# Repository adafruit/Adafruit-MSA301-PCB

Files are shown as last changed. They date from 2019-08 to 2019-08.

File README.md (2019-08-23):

## Adafruit MSA301 Triple Axis Accelerometer PCB

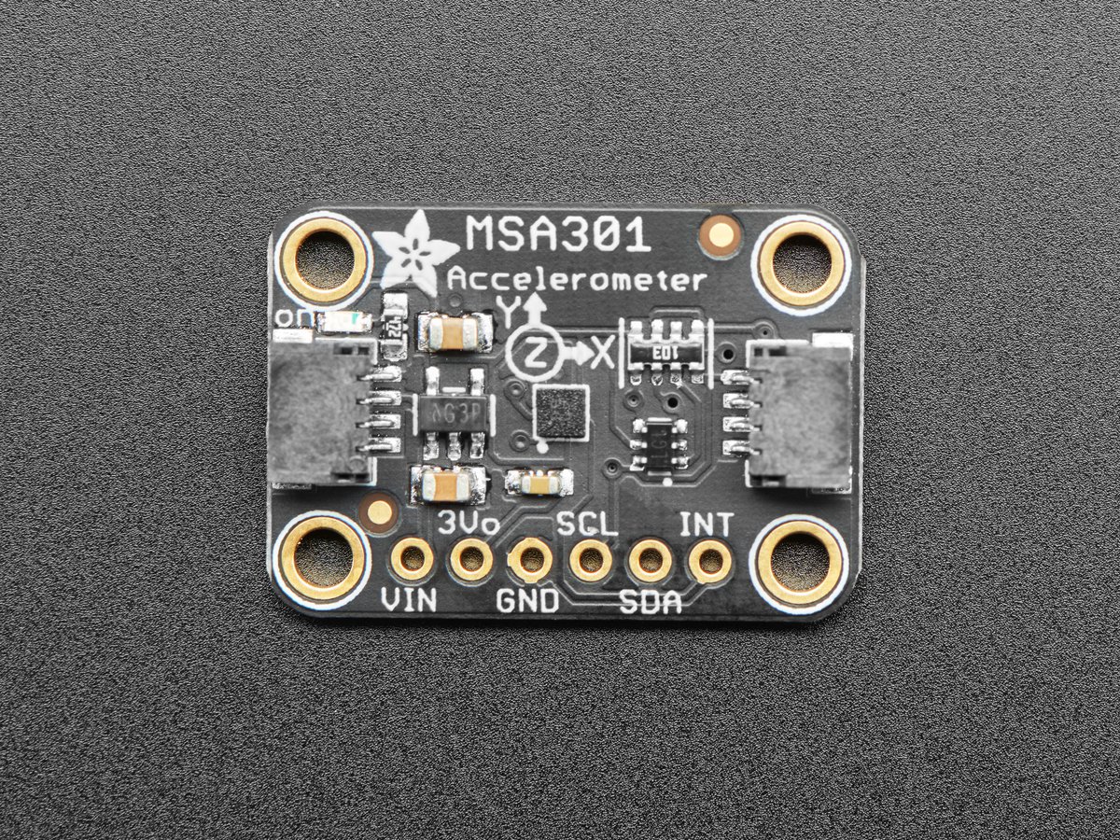
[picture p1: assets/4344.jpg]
<a href="http://www.adafruit.com/products/4344"><br/>
Click here to purchase one from the Adafruit shop</a>

PCB files for the Adafruit MSA301 Triple Axis Accelerometer. 

Format is EagleCAD schematic and board layout
* https://www.adafruit.com/product/4344

### Description

The MSA301 is a super small and low cost **triple-axis accelerometer**. It's inexpensive, but has just about every 'extra' you'd want in an accelerometer:

* Three axis sensing, 14-bit resolution
* ±2g/±4g/±8g/±16g selectable scaling
* I2C interface on fixed I2C address 0x26
* Interrupt output
* Multiple data rate options 1 Hz to 500 Hz
* As low as 2uA current draw in low power mode (just the chip itself, not including any supporting circuitry)
* Tap, Double-tap, orientation & freefall detection
To make life easier so you can focus on your important work, we've taken the MSA301 and put it onto a breakout PCB along with support circuitry to let you use this little wonder with 3.3V (Feather/Raspberry Pi) or 5V (Arduino/ Metro328) logic levels. Additionally since it speaks I2C you can easily connect it up with two wires (plus power and ground!).  We've even included [SparkFun qwiic](https://www.sparkfun.com/qwiic) compatible [STEMMA QT](https://learn.adafruit.com/introducing-adafruit-stemma-qt) connectors for the I2C bus so **you don't even need to solder!** Just wire up to your favorite micro and you can use our [CircuitPython/Python](https://github.com/adafruit/Adafruit_CircuitPython_MSA301) or [Arduino drivers](https://github.com/adafruit/Adafruit_MSA301] to easily interface with the MSA301 and get motion measurements ASAP.

### License

Adafruit invests time and resources providing this open source design, please support Adafruit and open-source hardware by purchasing products from [Adafruit](https://www.adafruit.com)!

Designed by Limor Fried/Ladyada for Adafruit Industries.

Creative Commons Attribution/Share-Alike, all text above must be included in any redistribution. 
See license.txt for additional details.

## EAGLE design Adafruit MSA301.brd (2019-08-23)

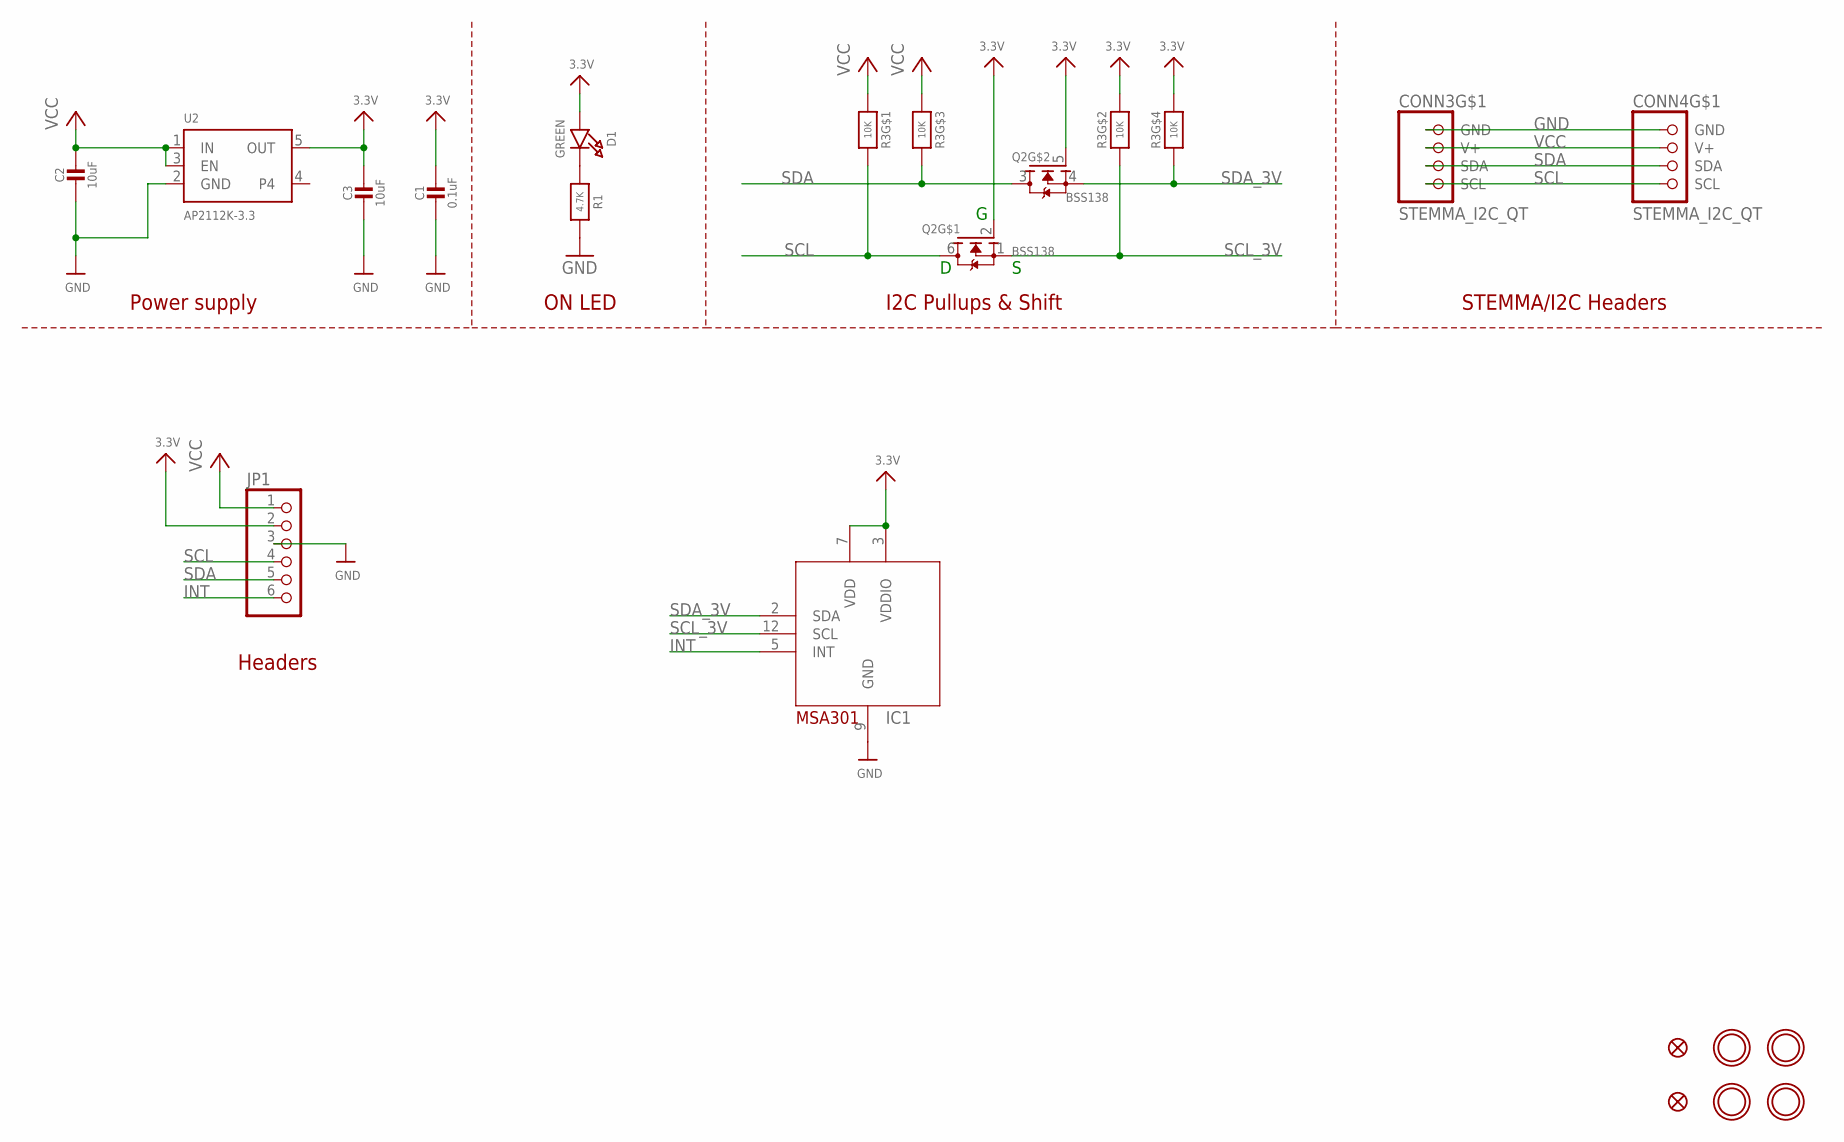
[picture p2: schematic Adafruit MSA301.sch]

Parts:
C1: 0.1uF; 0603-NO
C2, C3: 10uF; 0805-NO
CONN3, CONN4: STEMMA_I2C_QT; JST_SH4
D1: GREEN; CHIPLED_0603_NOOUTLINE
FID3, FID4: FIDUCIAL_1MM
IC1: MSA301; LGA12_2X2MM
JP1: HEADER-1X670MIL; 1X06_ROUND_70
Q2: BSS138; SOT363
R1: 4.7K; 0603-NO
R3: 10K; RESPACK_4X0603
U2: AP2112K-3.3; SOT23-5
U$1, U$17, U$19, U$21: MOUNTINGHOLE2.5; MOUNTINGHOLE_2.5_PLATED

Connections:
3.3V: C1.1, C3.1, D1.A, IC1.3 (VDDIO), IC1.7 (VDD), JP1.2, Q2.2 (G), Q2.5 (G), R3.2 (1), R3.4 (1), U2.5 (OUT)
GND: C1.2, C2.2, C3.2, CONN3.1 (GND), CONN4.1 (GND), IC1.9 (GND), JP1.3, R1.2, U2.2 (GND)
INT: IC1.5 (INT), JP1.6
unnamed: D1.C, R1.1
SCL: CONN3.4 (SCL), CONN4.4 (SCL), JP1.4, Q2.6 (D), R3.8 (2)
SCL_3V: IC1.12 (SCL), Q2.1 (S), R3.7 (2)
SDA: CONN3.3 (SDA), CONN4.3 (SDA), JP1.5, Q2.3 (D), R3.6 (2)
SDA_3V: IC1.2 (SDA), Q2.4 (S), R3.5 (2)
VCC: C2.1, CONN3.2 (V+), CONN4.2 (V+), JP1.1, R3.1, R3.3 (1), U2.1 (IN), U2.3 (EN)

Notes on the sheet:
Power supply
I2C Pullups & Shift
STEMMA/I2C Headers
Headers
ON LED

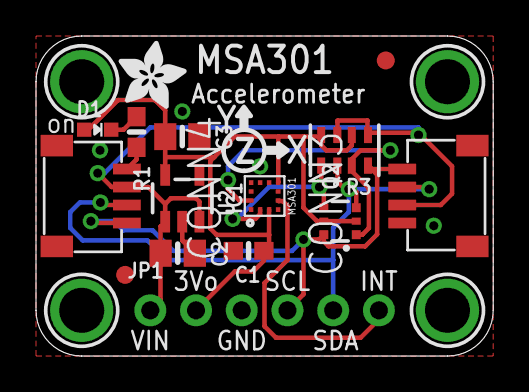
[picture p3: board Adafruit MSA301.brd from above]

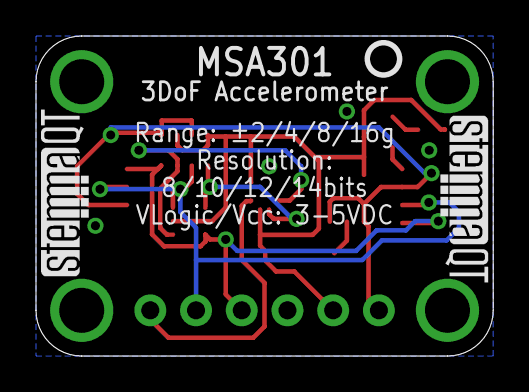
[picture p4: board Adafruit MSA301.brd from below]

Board: 2 copper layers, 25.4 x 17.8 mm, 22 parts (3 on the bottom side), 9 nets.

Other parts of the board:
U$22: ADAFRUIT_3.5MM
U$25: PCBFEAT-REV-040
U$30, U$31: STEMMAQT

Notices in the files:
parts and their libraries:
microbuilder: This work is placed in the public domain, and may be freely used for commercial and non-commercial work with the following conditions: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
